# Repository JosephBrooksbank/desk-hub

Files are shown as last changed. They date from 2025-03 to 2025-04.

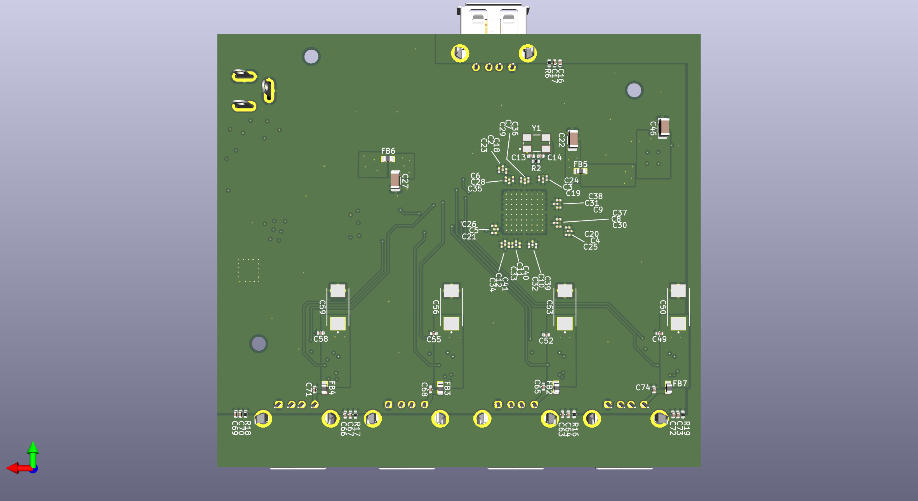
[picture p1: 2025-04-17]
PCB/Review Files/DeskHub_Bottom.png

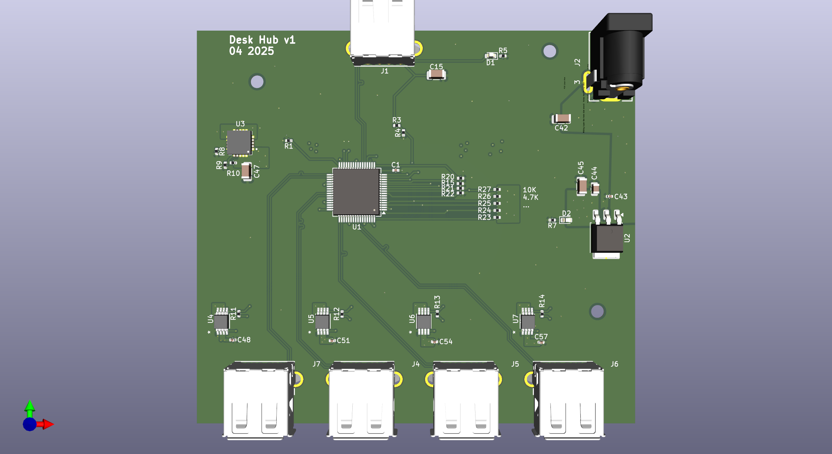
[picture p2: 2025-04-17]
PCB/Review Files/DeskHub_Top.png

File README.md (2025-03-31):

# desk-hub
A custom KM/USB switch for my desk. 

## Goals
- 10(+) USB Ports
- 2 input switchable
- Stable 5V power to all ports
- Separate overdraw protection
- Electronically controllable
- Visual indicator of port use and overdraw
- Multiple switching points to split input across machines
- USB3?

## Rationale 
Currently, I have two UGreen 4 port USB switches taped to my desk. Each morning I press the button on each to switch to work, and each afternoon I press the button to switch back. They cannot always reliably provide enough amps to each downstream port and my audio cuts out sometimes. Very occasionally they initialize incorrectly and I must remove all connections and reconnect them to gain control again. The downstream and upstream ports are also all on opposite sides, leading to many wires curling back on themselves. 

I aim to solve these issues in an overengineered board of my own design, as an opportunity to learn slightly higher speed PCB design and 4 layer boards.

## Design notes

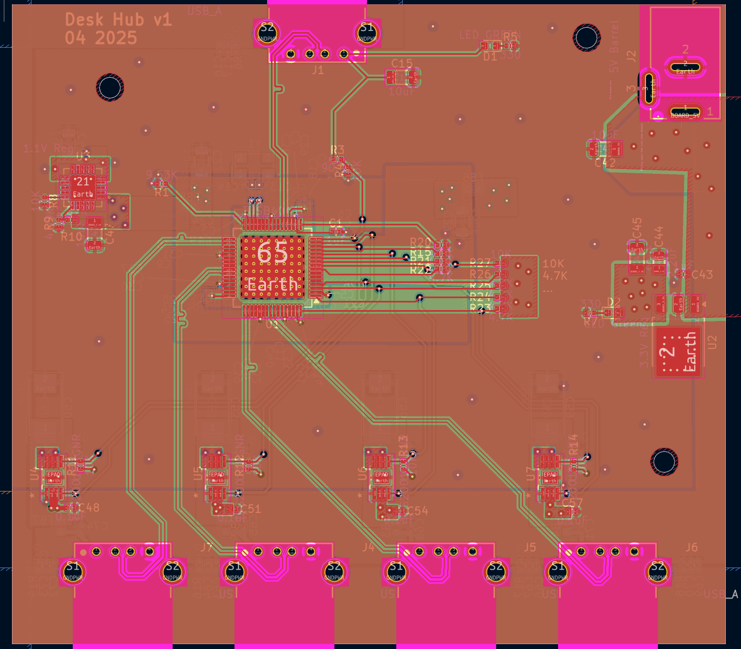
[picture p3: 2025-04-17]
PCB/Review Files/full_pcb.png

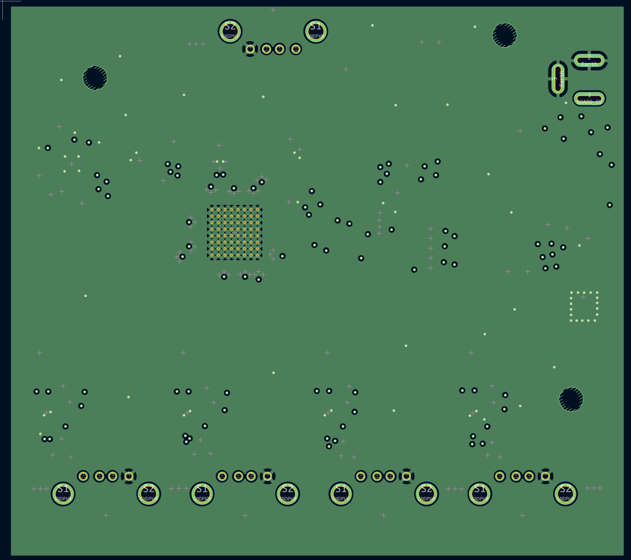
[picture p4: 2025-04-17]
PCB/Review Files/Cu1_pcb.png

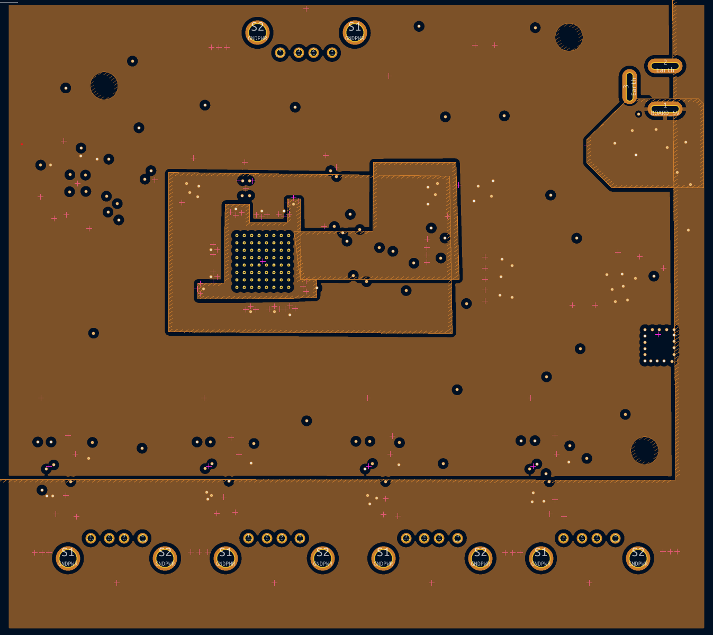
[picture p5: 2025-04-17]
PCB/Review Files/Cu2_pcb.png

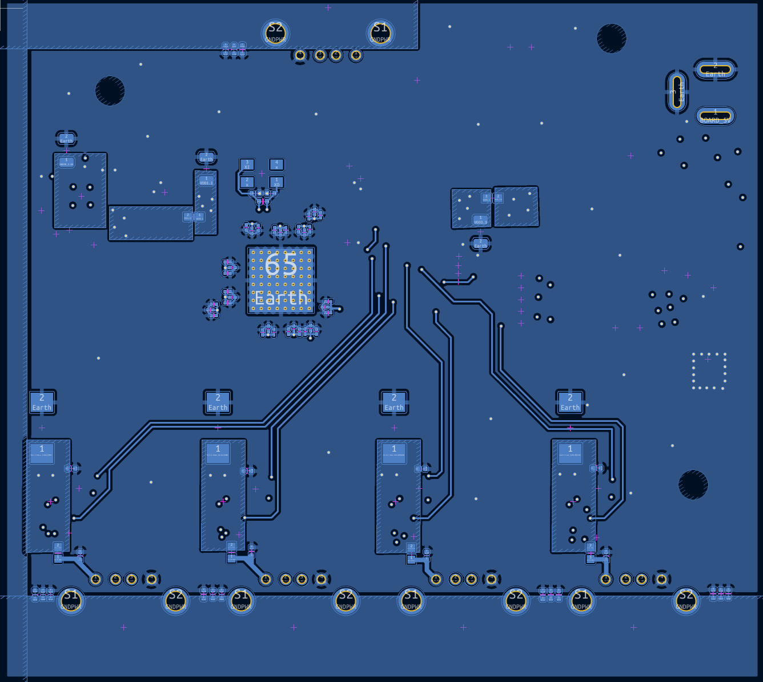
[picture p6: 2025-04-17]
PCB/Review Files/bCu_pcb.png

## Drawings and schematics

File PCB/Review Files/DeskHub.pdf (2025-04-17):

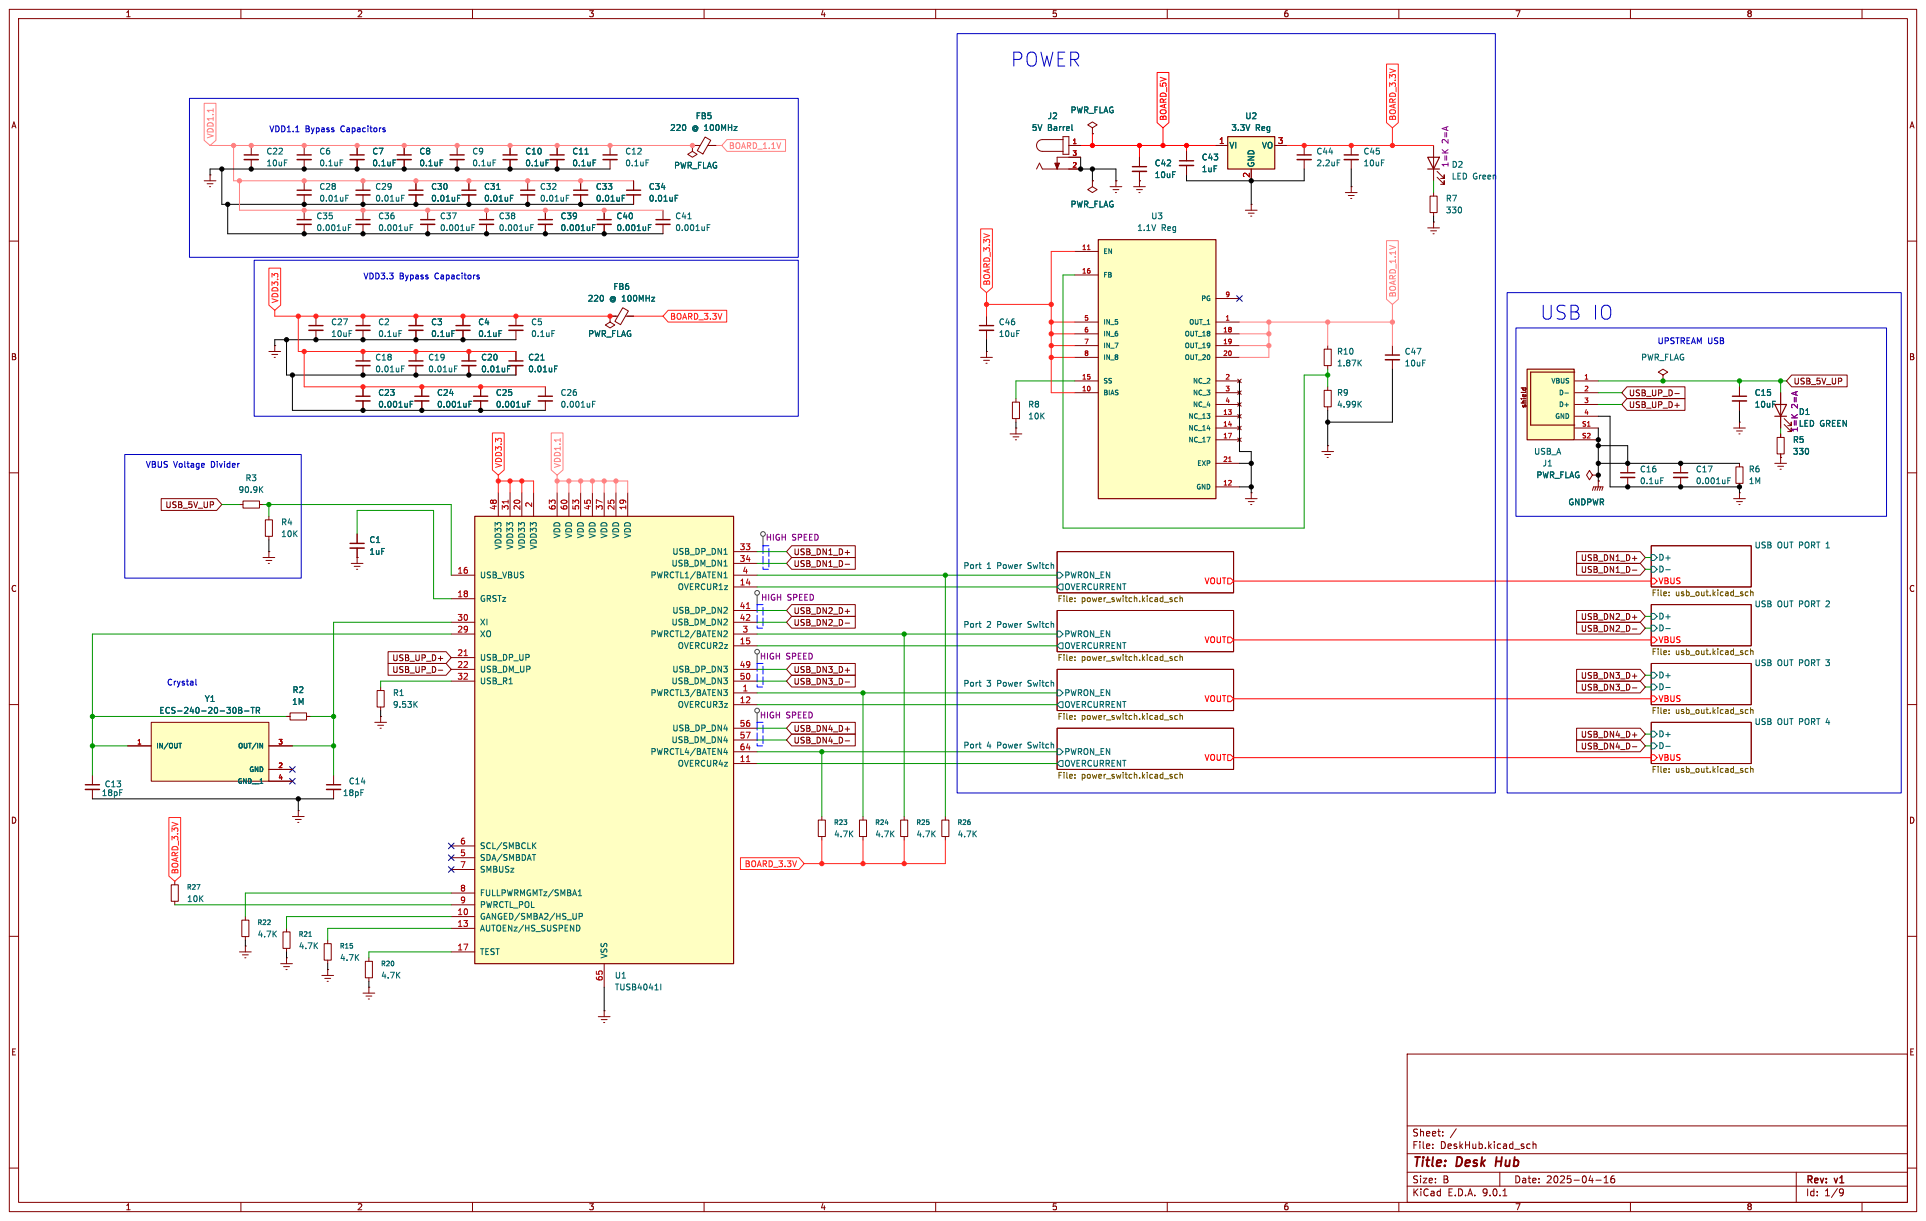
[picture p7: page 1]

VDD3.3 Bypass Capacitors VDD1.1 Bypass Capacitors

2 VDD 63 VDD 60 VDD 53 VDD 45 VDD 37 VSS 65 VDD 25 VDD 19 USB_DP_DN1 33 USB_DM_DN1 34 PWRCTL1/BATEN1 4 OVERCUR1z 14 USB_DP_DN2 41 USB_DM_DN2 42 PWRCTL2/BATEN2 3 OVERCUR2z 15 USB_DP_DN3 49 USB_DM_DN3 50 PWRCTL3/BATEN3 1 OVERCUR3z 12 USB_DP_DN4 56 USB_DM_DN4 57 PWRCTL4/BATEN4 64 OVERCUR4z 11 U1 TUSB4041I

File: DeskHub.kicad_sch Sheet: /
Id: 1/9 Title: Desk Hub

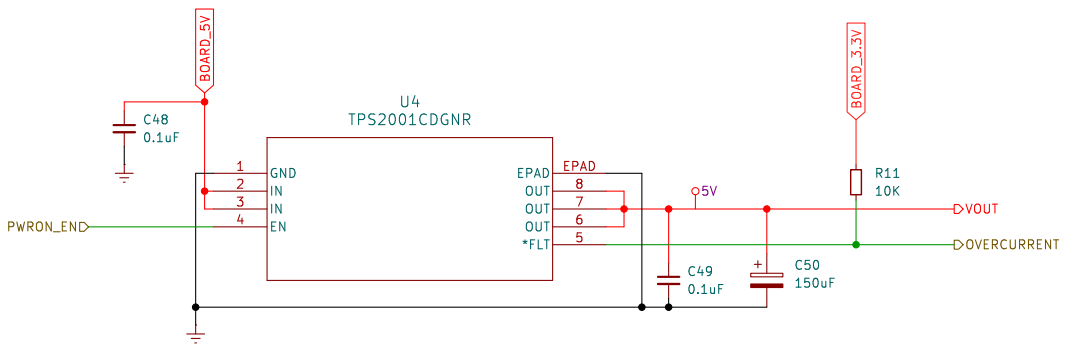
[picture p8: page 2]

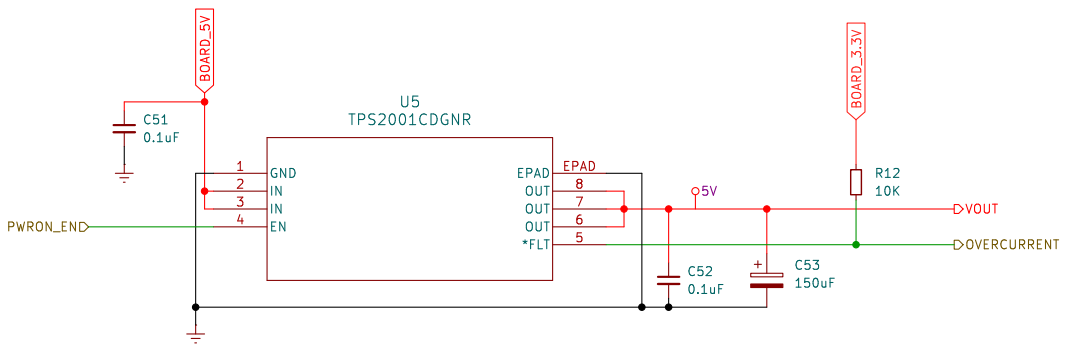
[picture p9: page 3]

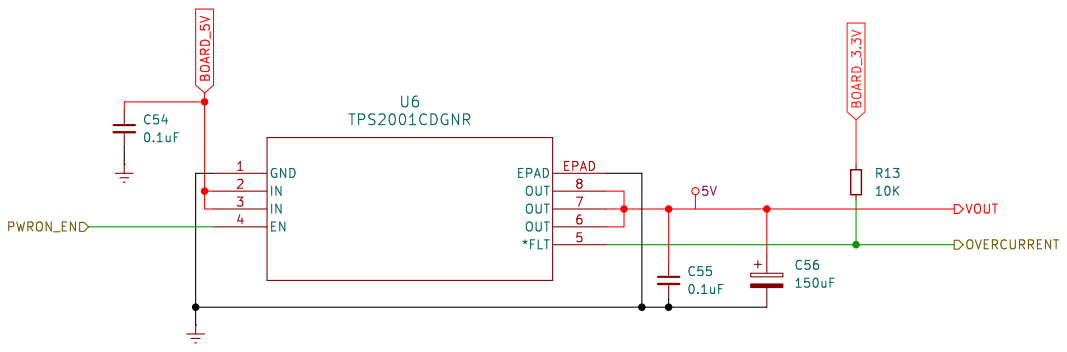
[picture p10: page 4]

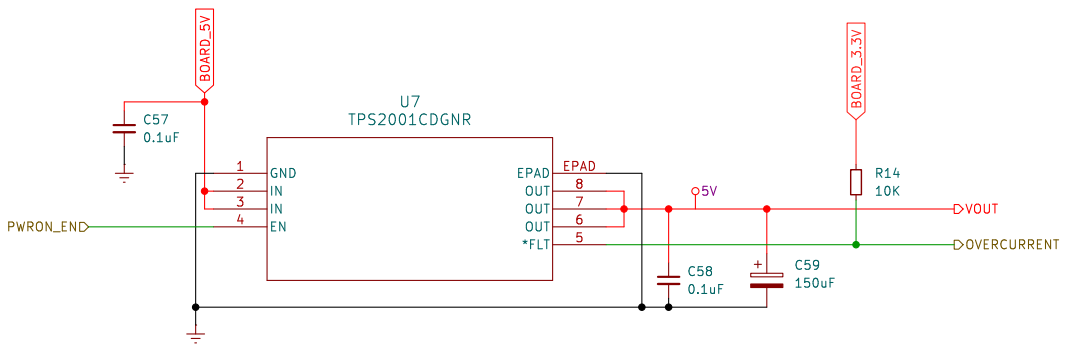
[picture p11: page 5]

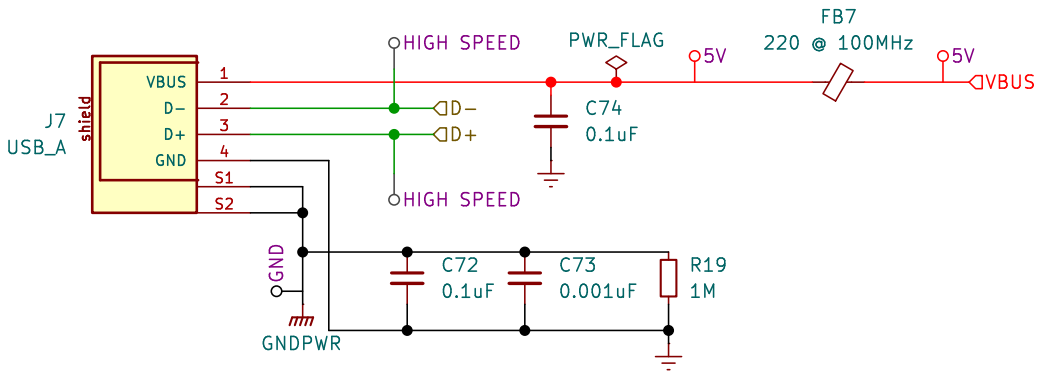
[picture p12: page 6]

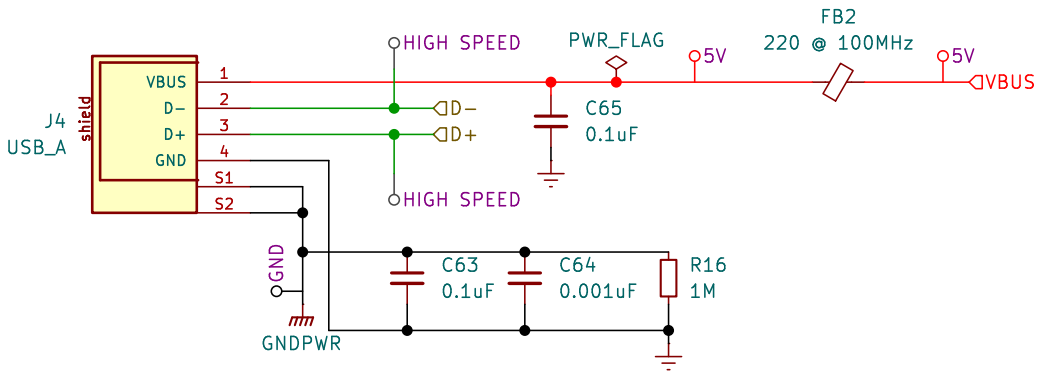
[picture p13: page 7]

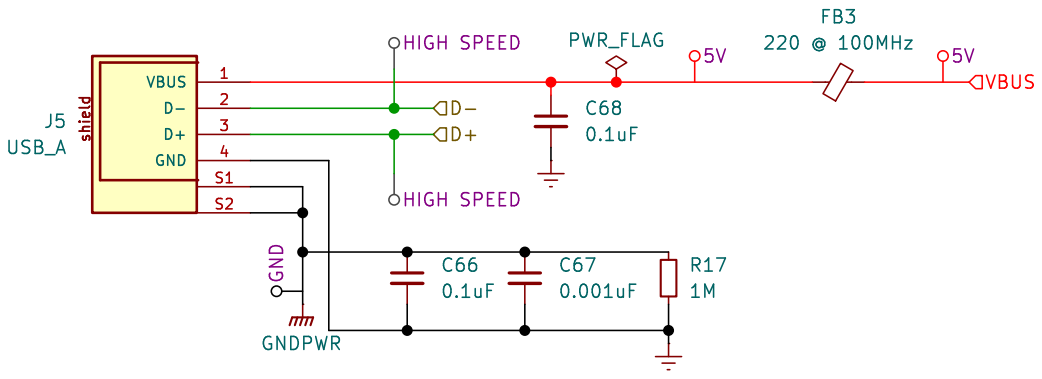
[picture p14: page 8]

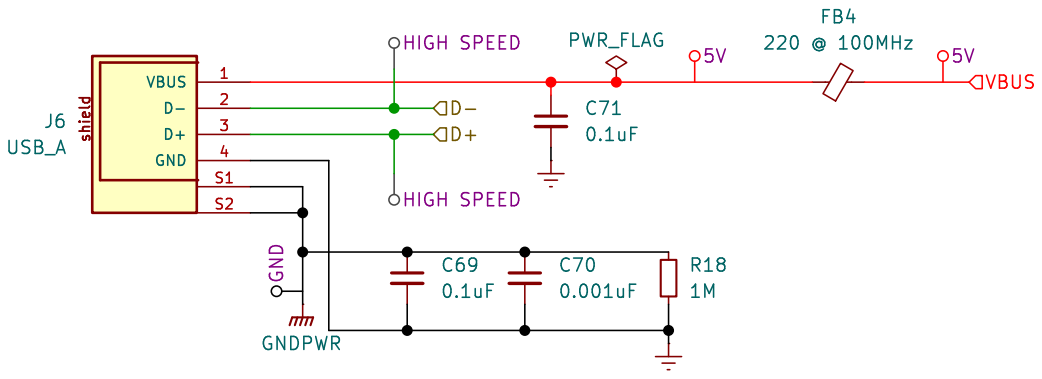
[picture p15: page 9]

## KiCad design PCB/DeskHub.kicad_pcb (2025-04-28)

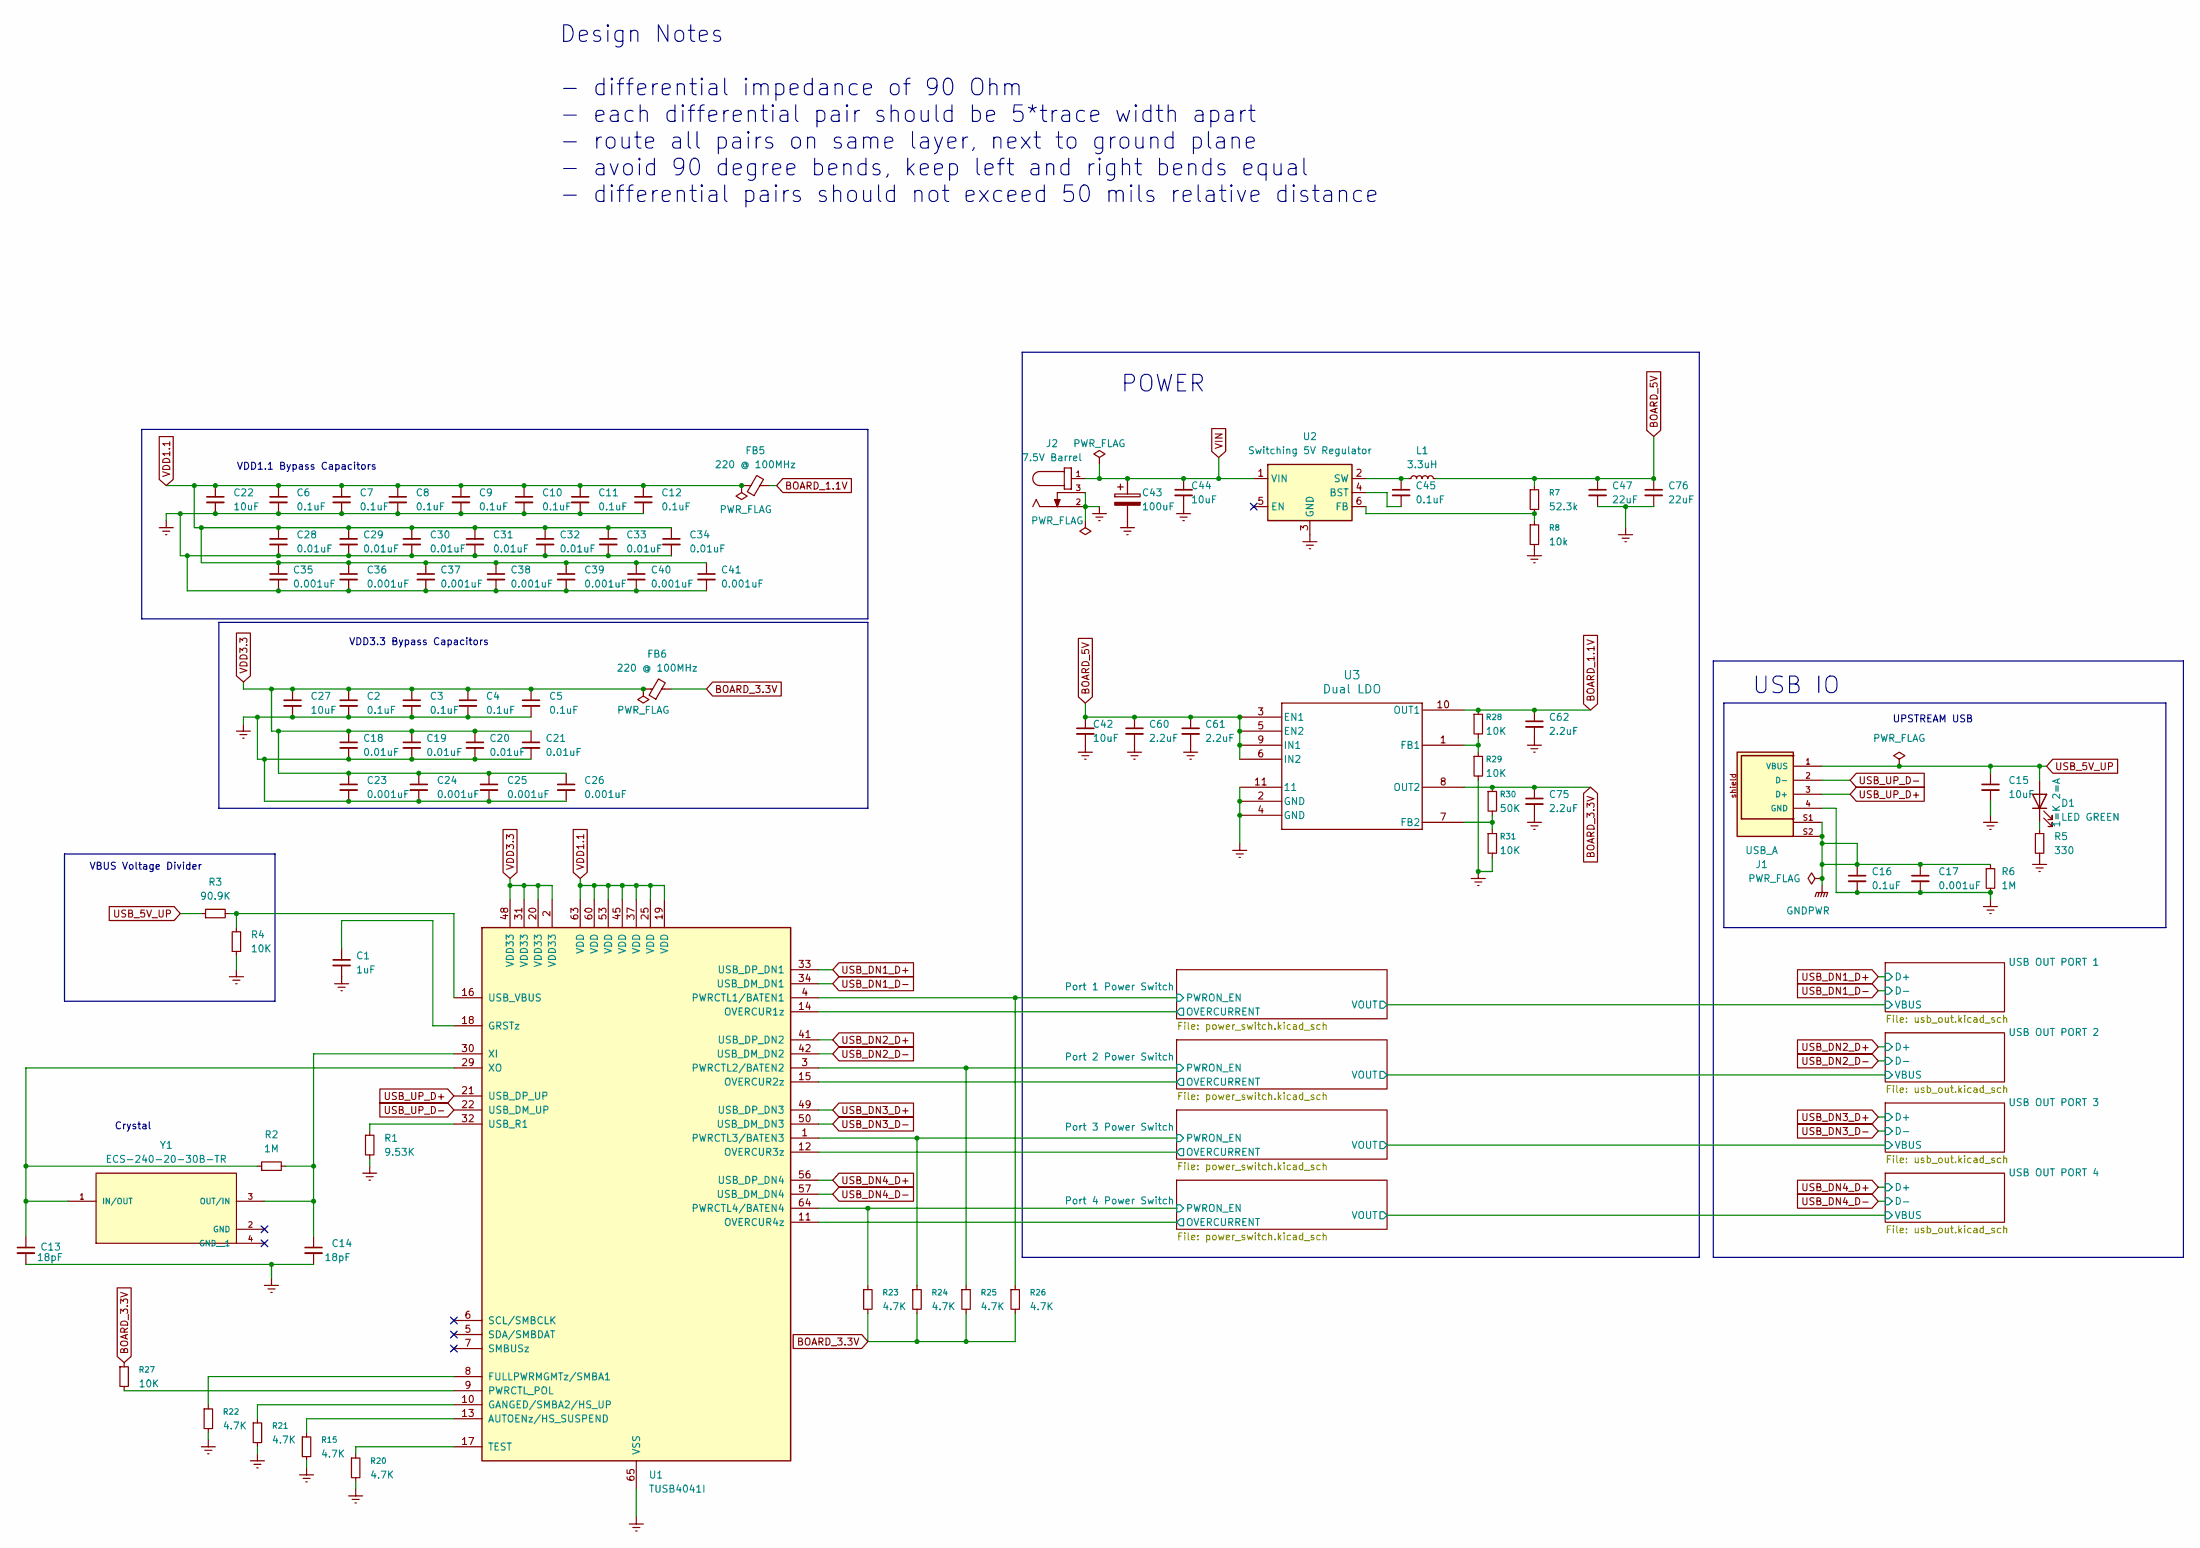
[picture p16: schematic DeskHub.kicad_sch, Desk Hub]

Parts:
C1: 1uF; C_0402_1005Metric
C2, C3, C4, C5, C6, C7, C8, C9, C10, C11, C12: 0.1uF; C_0201_0603Metric
C13, C14: 18pF; C_0402_1005Metric
C15, C22, C27, C42, C44: 10uF; C_1206_3216Metric
C16, C45: 0.1uF; C_0402_1005Metric
C17: 0.001uF; C_0402_1005Metric
C18, C19, C20, C21, C28, C29, C30, C31, C32, C33, C34: 0.01uF; C_0201_0603Metric
C23, C24, C25, C26, C35, C36, C37, C38, C39, C40, C41: 0.001uF; C_0201_0603Metric
C43: 100uF; CP_Elec_6.3x7.7
C47, C76: 22uF; C_0201_0603Metric
C60, C61, C62, C75: 2.2uF; C_0805_2012Metric
D1: LED GREEN; LED_0603_1608Metric
FB5, FB6: 220 @ 100MHz; BEADC1608X95N
J1: USB_A; 61400416021
J2: 7.5V Barrel; 694108301002
L1: 3.3uH; NRS5030T3R3MMGJ
R1: 9.53K; R_0402_1005Metric
R2, R6: 1M; R_0402_1005Metric
R3: 90.9K; R_0402_1005Metric
R4, R27, R28, R29, R31: 10K; R_0402_1005Metric
R5: 330; R_0402_1005Metric
R7: 52.3k; R_0402_1005Metric
R8: 10k; R_0402_1005Metric
R15, R20, R21, R22, R23, R24, R25, R26: 4.7K; R_0402_1005Metric
R30: 50K; R_0402_1005Metric
U1: TUSB4041I; HTQFP-64-1EP_10x10mm_P0.5mm_EP8x8mm_Mask4.4x4.4mm_ThermalVi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
U2: Switching 5V Regulator; SOT-563
U3: Dual LDO; SON_1PDSQR_TEX
Y1: ECS-240-20-30B-TR; XTAL_ECS-240-20-30B-TR

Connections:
/Port 1 Power Switch/OVERCURRENT: U1.14 (OVERCUR1z); also elsewhere on the board
/Port 1 Power Switch/PWRON_EN: R26.1, U1.4 (PWRCTL1/BATEN1); also elsewhere on the board
/Port 2 Power Switch/OVERCURRENT: U1.15 (OVERCUR2z); also elsewhere on the board
/Port 2 Power Switch/PWRON_EN: R25.1, U1.3 (PWRCTL2/BATEN2); also elsewhere on the board
/Port 3 Power Switch/OVERCURRENT: U1.12 (OVERCUR3z); also elsewhere on the board
/Port 3 Power Switch/PWRON_EN: R24.1, U1.1 (PWRCTL3/BATEN3); also elsewhere on the board
/Port 4 Power Switch/OVERCURRENT: U1.11 (OVERCUR4z); also elsewhere on the board
/Port 4 Power Switch/PWRON_EN: R23.1, U1.64 (PWRCTL4/BATEN4); also elsewhere on the board
BOARD_1.1V: C62.1, FB5.2, R28.1, U3.10 (OUT1)
BOARD_3.3V: C75.1, FB6.2, R23.2, R24.2, R25.2, R26.2, R27.1, R30.1, U3.8 (OUT2); also elsewhere on the board
BOARD_5V: C42.1, C47.1, C60.1, C61.1, C76.1, L1.2, R7.1, U3.3 (EN1), U3.5 (EN2), U3.6 (IN2), U3.9 (IN1); also elsewhere on the board
Earth: C1.2, C2.2, C3.2, C4.2, C5.2, C6.2, C7.2, C8.2, C9.2, C10.2, C11.2, C12.2, C13.2, C14.2, C15.2, C16.2, C17.2, C18.2, C19.2, C20.2, C21.2, C22.2, C23.2, C24.2, C25.2, C26.2, C27.2, C28.2, C29.2, C30.2, C31.2, C32.2, C33.2, C34.2, C35.2, C36.2, C37.2, C38.2, C39.2, C40.2, C41.2, C42.2, C43.2, C44.2, C47.2, C60.2, C61.2, C62.2, C75.2, C76.2, J1.4 (GND), J2.2, J2.3, R1.2, R4.1, R5.2, R6.2, R8.2, R15.2, R20.2, R21.2, R22.2, R29.2, R31.2, U1.65 (VSS), U2.3 (GND), U3.2 (GND), U3.4 (GND), U3.11; also elsewhere on the board
GNDPWR: C16.1, C17.1, J1.S1, J1.S2, R6.1; also elsewhere on the board
unnamed: D1.1 (K), R5.1
unnamed: R15.1, U1.13 (AUTOENz/HS_SUSPEND)
unnamed: R22.1, U1.8 (FULLPWRMGMTz/SMBA1)
unnamed: R21.1, U1.10 (GANGED/SMBA2/HS_UP)
unnamed: C1.1, U1.18 (GRSTz)
unnamed: R27.2, U1.9 (PWRCTL_POL)
unnamed: R20.1, U1.17 (TEST)
unnamed: R1.1, U1.32 (USB_R1)
unnamed: R3.2, R4.2, U1.16 (USB_VBUS)
unnamed: C14.1, R2.2, U1.30 (XI), Y1.3 (OUT/IN)
unnamed: C13.1, R2.1, U1.29 (XO), Y1.1 (IN/OUT)
unnamed: C45.2, U2.4 (BST)
unnamed: R7.2, R8.1, U2.6 (FB)
unnamed: C45.1, L1.1, U2.2 (SW)
unnamed: R28.2, R29.1, U3.1 (FB1)
unnamed: R30.2, R31.1, U3.7 (FB2)
USB_5V_UP: C15.1, D1.2 (A), J1.1 (VBUS), R3.1
USB_DN1_D+: U1.33 (USB_DP_DN1); also elsewhere on the board
USB_DN1_D-: U1.34 (USB_DM_DN1); also elsewhere on the board
USB_DN2_D+: U1.41 (USB_DP_DN2); also elsewhere on the board
USB_DN2_D-: U1.42 (USB_DM_DN2); also elsewhere on the board
USB_DN3_D+: U1.49 (USB_DP_DN3); also elsewhere on the board
USB_DN3_D-: U1.50 (USB_DM_DN3); also elsewhere on the board
USB_DN4_D+: U1.56 (USB_DP_DN4); also elsewhere on the board
USB_DN4_D-: U1.57 (USB_DM_DN4); also elsewhere on the board
USB_UP_D+: J1.3 (D+), U1.21 (USB_DP_UP)
USB_UP_D-: J1.2 (D-), U1.22 (USB_DM_UP)
VDD1.1: C6.1, C7.1, C8.1, C9.1, C10.1, C11.1, C12.1, C22.1, C28.1, C29.1, C30.1, C31.1, C32.1, C33.1, C34.1, C35.1, C36.1, C37.1, C38.1, C39.1, C40.1, C41.1, FB5.1, U1.19 (VDD), U1.25 (VDD), U1.37 (VDD), U1.45 (VDD), U1.53 (VDD), U1.60 (VDD), U1.63 (VDD)
VDD3.3: C2.1, C3.1, C4.1, C5.1, C18.1, C19.1, C20.1, C21.1, C23.1, C24.1, C25.1, C26.1, C27.1, FB6.1, U1.2 (VDD33), U1.20 (VDD33), U1.31 (VDD33), U1.48 (VDD33)
VIN: C43.1, C44.1, J2.1, U2.1 (VIN)

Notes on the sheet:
UPSTREAM USB
VDD1.1 Bypass Capacitors
Design Notes - differential impedance of 90 Ohm - each differential pair should be 5*trace width apart - route all pairs on same layer, next to ground plane - avoid 90 degree bends, keep left and right bends equal - differential pairs should not exceed 50 mils relative distance
VDD3.3 Bypass Capacitors
USB IO
Crystal
POWER
VBUS Voltage Divider

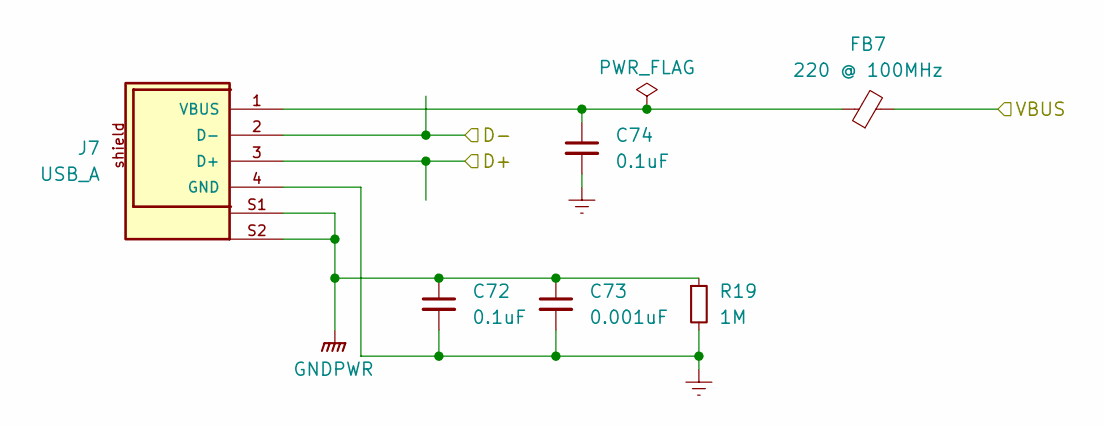
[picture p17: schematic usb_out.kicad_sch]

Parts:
C72, C74: 0.1uF; C_0402_1005Metric
C73: 0.001uF; C_0402_1005Metric
FB7: 220 @ 100MHz; BEADC1608X95N
J7: USB_A; 61400416021
R19: 1M; R_0402_1005Metric

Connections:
/Port 1 Power Switch/VOUT: FB7.2; also elsewhere on the board
Earth: C72.2, C73.2, C74.2, J7.4 (GND), R19.2; also elsewhere on the board
GNDPWR: C72.1, C73.1, J7.S1, J7.S2, R19.1; also elsewhere on the board
unnamed: C74.1, FB7.1, J7.1 (VBUS)
USB_DN1_D+: J7.3 (D+); also elsewhere on the board
USB_DN1_D-: J7.2 (D-); also elsewhere on the board

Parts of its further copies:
C63, C65, C66, C68, C69, C71: 0.1uF; C_0402_1005Metric
C64, C67, C70: 0.001uF; C_0402_1005Metric
FB2, FB3, FB4: 220 @ 100MHz; BEADC1608X95N
J4, J5, J6: USB_A; 61400416021
R16, R17, R18: 1M; R_0402_1005Metric

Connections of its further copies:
/Port 2 Power Switch/VOUT: FB2.2; also elsewhere on the board
/Port 3 Power Switch/VOUT: FB3.2; also elsewhere on the board
/Port 4 Power Switch/VOUT: FB4.2; also elsewhere on the board
Earth: C63.2, C64.2, C65.2, C66.2, C67.2, C68.2, C69.2, C70.2, C71.2, J4.4 (GND), J5.4 (GND), J6.4 (GND), R16.2, R17.2, R18.2; also elsewhere on the board
GNDPWR: C63.1, C64.1, C66.1, C67.1, C69.1, C70.1, J4.S1, J4.S2, J5.S1, J5.S2, J6.S1, J6.S2, R16.1, R17.1, R18.1; also elsewhere on the board
unnamed: C65.1, FB2.1, J4.1 (VBUS)
unnamed: C68.1, FB3.1, J5.1 (VBUS)
unnamed: C71.1, FB4.1, J6.1 (VBUS)
USB_DN2_D+: J4.3 (D+); also elsewhere on the board
USB_DN2_D-: J4.2 (D-); also elsewhere on the board
USB_DN3_D+: J5.3 (D+); also elsewhere on the board
USB_DN3_D-: J5.2 (D-); also elsewhere on the board
USB_DN4_D+: J6.3 (D+); also elsewhere on the board
USB_DN4_D-: J6.2 (D-); also elsewhere on the board

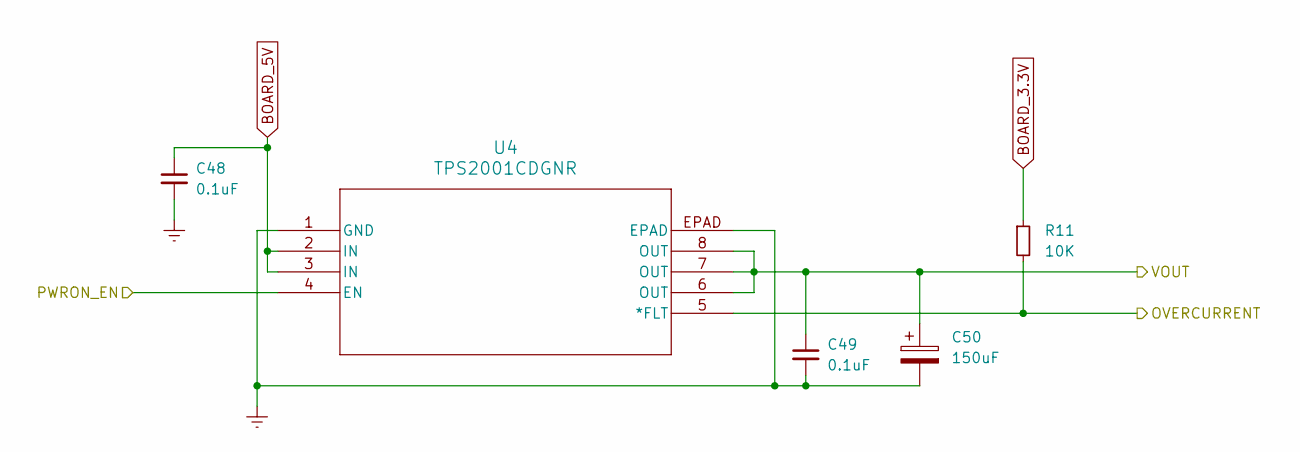
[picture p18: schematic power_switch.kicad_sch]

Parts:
C48, C49: 0.1uF; C_0402_1005Metric
C50: 150uF; CAP_EEFCX0J151XR
R11: 10K; R_0402_1005Metric
U4: TPS2001CDGNR; DGN8_1P89X1P57

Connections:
/Port 1 Power Switch/OVERCURRENT: R11.2, U4.5 (*FLT); also elsewhere on the board
/Port 1 Power Switch/PWRON_EN: U4.4 (EN); also elsewhere on the board
/Port 1 Power Switch/VOUT: C49.1, C50.1, U4.6 (OUT), U4.7 (OUT), U4.8 (OUT); also elsewhere on the board
BOARD_3.3V: R11.1; also elsewhere on the board
BOARD_5V: C48.1, U4.2 (IN), U4.3 (IN); also elsewhere on the board
Earth: C48.2, C49.2, C50.2, U4.1 (GND), U4.EPAD; also elsewhere on the board

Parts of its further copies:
C51, C52, C54, C55, C57, C58: 0.1uF; C_0402_1005Metric
C53, C56, C59: 150uF; CAP_EEFCX0J151XR
R12, R13, R14: 10K; R_0402_1005Metric
U5, U6, U7: TPS2001CDGNR; DGN8_1P89X1P57

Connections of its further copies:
/Port 2 Power Switch/OVERCURRENT: R12.2, U5.5 (*FLT); also elsewhere on the board
/Port 2 Power Switch/PWRON_EN: U5.4 (EN); also elsewhere on the board
/Port 2 Power Switch/VOUT: C52.1, C53.1, U5.6 (OUT), U5.7 (OUT), U5.8 (OUT); also elsewhere on the board
/Port 3 Power Switch/OVERCURRENT: R13.2, U6.5 (*FLT); also elsewhere on the board
/Port 3 Power Switch/PWRON_EN: U6.4 (EN); also elsewhere on the board
/Port 3 Power Switch/VOUT: C55.1, C56.1, U6.6 (OUT), U6.7 (OUT), U6.8 (OUT); also elsewhere on the board
/Port 4 Power Switch/OVERCURRENT: R14.2, U7.5 (*FLT); also elsewhere on the board
/Port 4 Power Switch/PWRON_EN: U7.4 (EN); also elsewhere on the board
/Port 4 Power Switch/VOUT: C58.1, C59.1, U7.6 (OUT), U7.7 (OUT), U7.8 (OUT); also elsewhere on the board
BOARD_3.3V: R12.1, R13.1, R14.1; also elsewhere on the board
BOARD_5V: C51.1, C54.1, C57.1, U5.2 (IN), U5.3 (IN), U6.2 (IN), U6.3 (IN), U7.2 (IN), U7.3 (IN); also elsewhere on the board
Earth: C51.2, C52.2, C53.2, C54.2, C55.2, C56.2, C57.2, C58.2, C59.2, U5.1 (GND), U5.EPAD, U6.1 (GND), U6.EPAD, U7.1 (GND), U7.EPAD; also elsewhere on the board

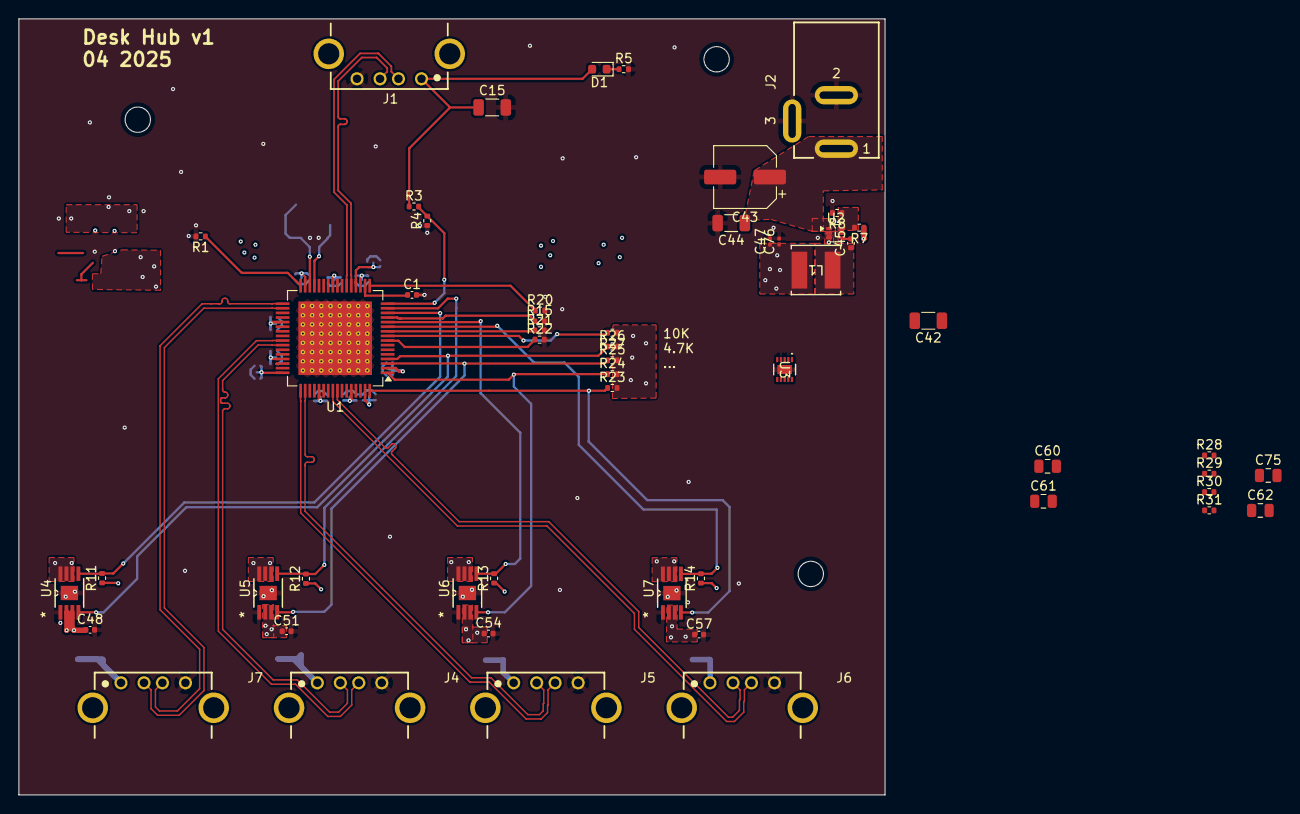
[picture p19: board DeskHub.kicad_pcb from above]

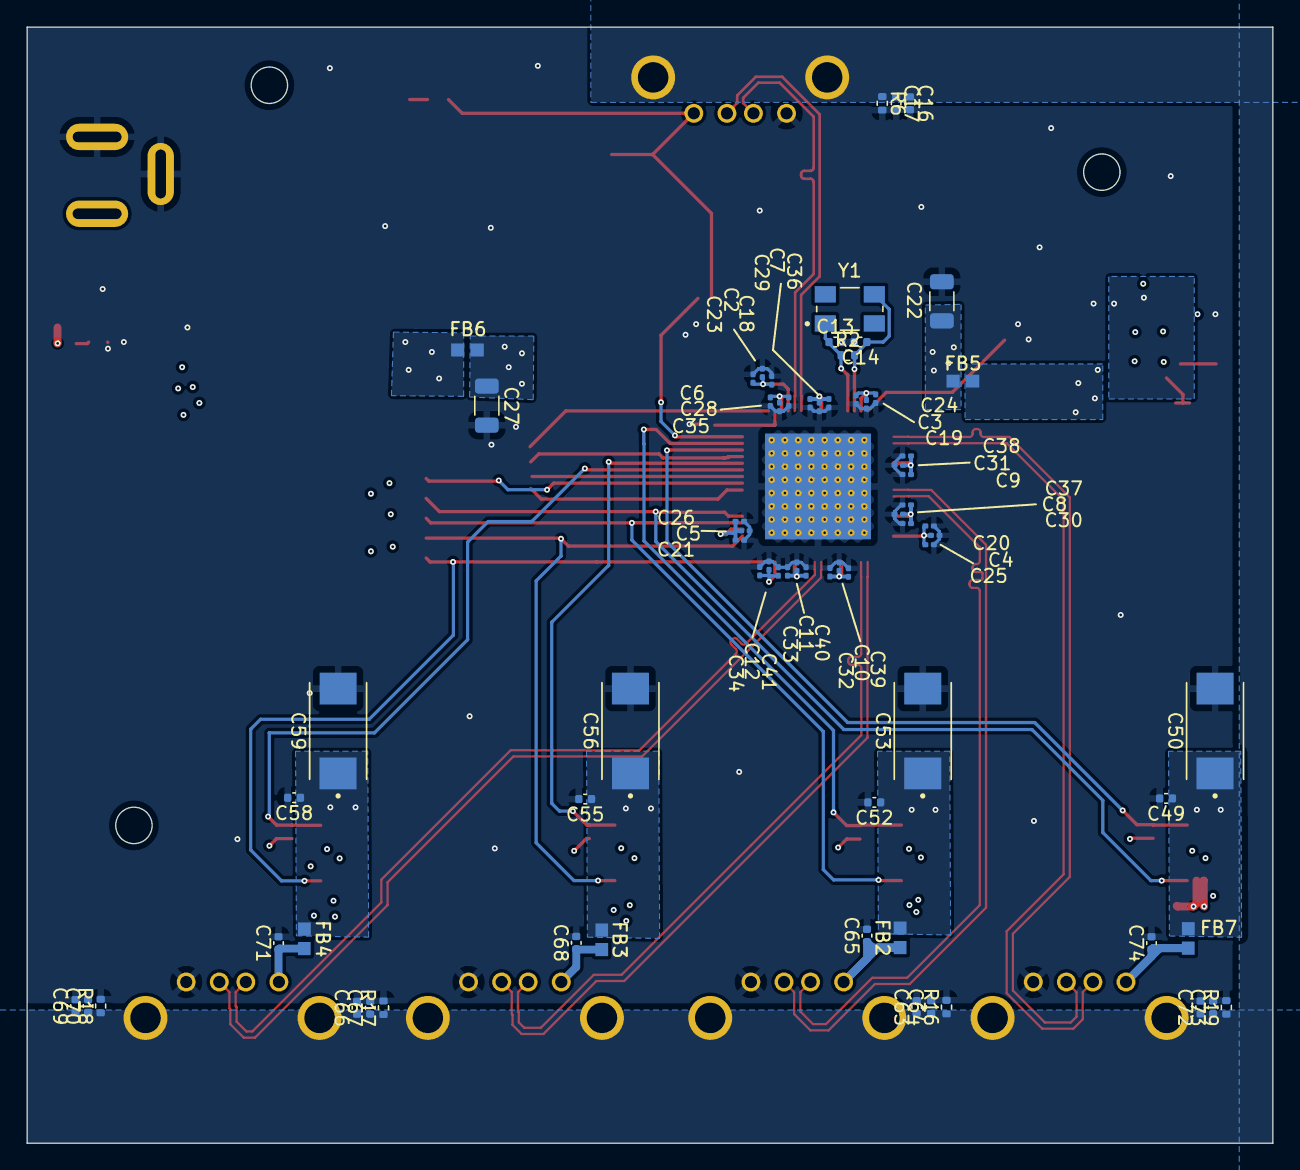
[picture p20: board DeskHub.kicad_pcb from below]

Board: 4 copper layers, 94.0 x 84.2 mm, 126 parts (72 on the bottom side), 51 nets.

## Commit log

2025-03-31 comply with ERC
    [DeskHub.kicad_sch, power_switch.kicad_sch, usb_out.kicad_sch]
2025-03-31 add net classes
    [DeskHub.kicad_sch, power_switch.kicad_sch, usb_out.kicad_sch]
2025-03-31 saved? unsure what
    [DeskHub.kicad_sch]
2025-03-31 maybe net classes this time
    [DeskHub.kicad_sch]
2025-04-01 Completed schematic!
    [DeskHub.kicad_sch]
2025-04-01 adjust schematic to match real components, assign footprints
    [DeskHub.kicad_pcb, DeskHub.kicad_sch, power_switch.kicad_sch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]
2025-04-01 begin work on pcb placement... pray for me
    [DeskHub.kicad_pcb]
2025-04-01 final save of the night
    [DeskHub.kicad_pcb, DeskHub.kicad_sch]
2025-04-02 organized bypass caps into groups
    [DeskHub.kicad_pcb]
2025-04-02 routed 4041I bypass caps
    [DeskHub.kicad_pcb]
2025-04-04 route usb diffs, power for 1 usb partially complete
    [DeskHub.kicad_pcb]
2025-04-04 cont. work on usb routing
    [DeskHub.kicad_pcb]
2025-04-04 began power routing
    [DeskHub.kicad_pcb]
2025-04-07 1.1v power net
    [DeskHub.kicad_pcb]
2025-04-07 routing done!
    [DeskHub.kicad_pcb]
2025-04-07 update physical board stats
2025-04-08 finished v1 of board
    [DeskHub.kicad_pcb]
2025-04-08 Redefine constraints
    using 0.2mm vias doubles the price of the board, so I am going to try
    and not use such small vias.
2025-04-09 pcb v1.1, modified to conform to JLC standards
    [DeskHub.kicad_pcb]
2025-04-09 pcb v1.2 with JLC mappings
    [DeskHub-CuBottom.gbr, DeskHub-CuIn1.gbr, DeskHub-CuIn2.gbr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]
2025-04-09 space out vias, add stiching vias, remove teardrops
    [DeskHub-CuBottom.gbr, DeskHub-CuIn1.gbr, DeskHub-CuIn2.gbr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]
2025-04-17 pcb v2.0 condensed
    [DeskHub.kicad_pcb]
2025-04-17 pcb v2.01 reddit review post
    [DeskHub-CuBottom.gbr, DeskHub-CuIn1.gbr, DeskHub-CuIn2.gbr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]
2025-04-25 switching vreg
    [DeskHub.kicad_sch]
2025-04-25 add back barrel jack
    [DeskHub.kicad_sch]
2025-04-25 add switching power supply
    [DeskHub.kicad_sch]
2025-04-28 work on pcb new power
    [DeskHub.kicad_pcb, DeskHub.kicad_sch]
